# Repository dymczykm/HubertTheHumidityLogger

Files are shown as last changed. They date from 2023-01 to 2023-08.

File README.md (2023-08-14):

# Hubert the Humidity Logger

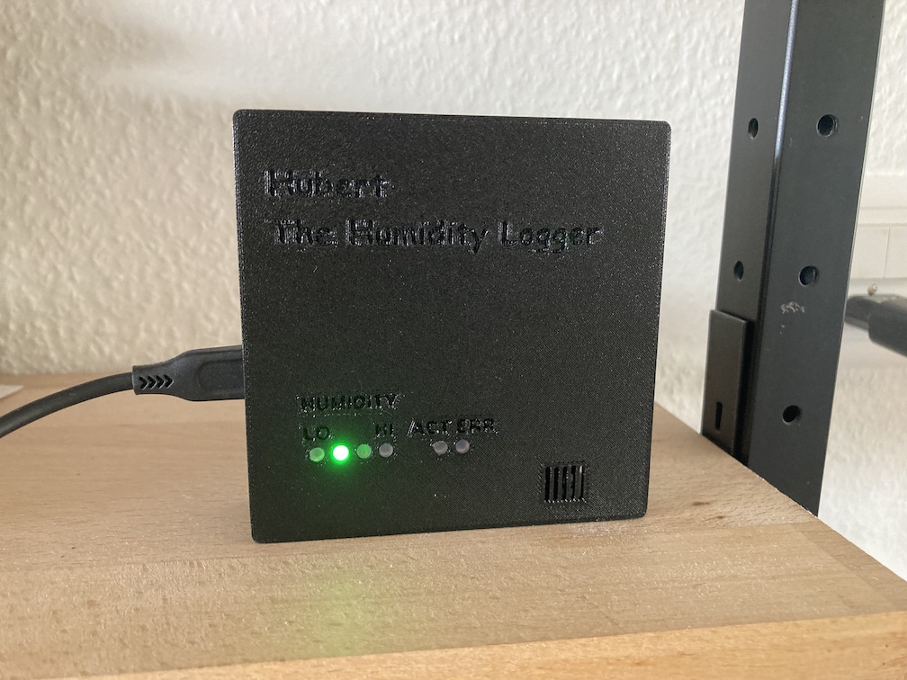
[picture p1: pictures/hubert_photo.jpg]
Photo of Hubert


Huber the Humidity Logger is a project of an IoT device that measures the relative humidity, temperature and pressure and reports it back to a remote server using the built-in 4G modem. I created this project as I couldn't find a device off the shelf that could log humidity using the cellular network and would not cost an arm and a leg.

Hubert can use a HTTP POST action to submit data to virtually any server, either running in the cloud (I tested it with https://io.adafruit.com/) or maintained on your own (my Hubert is submitting data to a Raspberry Pi running InfluxDB).

Hubert is build around (Makerfabs Maduino Zero 4G LTE)[ttps://www.makerfabs.com/maduino-zero-4g-lte-sim7600.html] and loosely inspired by the [DIY Life 4G air quality weather station](https://www.the-diy-life.com/diy-4g-air-quality-and-environment-monitor-record-data-anywhere/).

For more details, please refer to the project page: https://dymczyk.com/hubert-the-humidity-logger

## Hardware

To build Hubert, you need the following components:
- Maduino Zero 4G/LTE board: https://www.makerfabs.com/maduino-zero-4g-lte-sim7600.html (includes an Arduino Zero compatible MCU + a Simcom 7600 modem)
- Hubert breakout board with a bunch of LEDs and a connector for the humidity sensor: KiCad files in `hardware/HumidityLoggerBreakout`
- BME280 sensor compatible with 3.3V supply [(Aliexpress item I used)](https://www.aliexpress.com/item/32862445164.html)
- A SIM card with some data allowance to post the humidity/temperature/pressure measurements

## Firmware

The firmware of Hubert is written in Arduino IDE and is located in `firmware/humidity_logger`.

The firmware does three main things:
1. Triggers the measurement process of BME280
2. POSTs the measurements to a remote server
3. Puts the modem and the MCU to sleep to save power

To adapt it to your application, you mostly need to put the credentials to access the server in `influxdb.h` file:
```
#define USER "xxx"
#define PASSWORD "xxx"
#define DB_URL "xxx"
```

## Remote server

Hubert uses a 4G connection to POST data to an InfluxDB database that resides on a remote server. In my case, it is a Raspberry Pi running continuously InfluxDB and Grafana to visualize the results in a nice dashboard.

## Case

I've designed a 3D printed case for Hubert, you can find the STL files for the top and the bottom in `hardware/case_stl`:

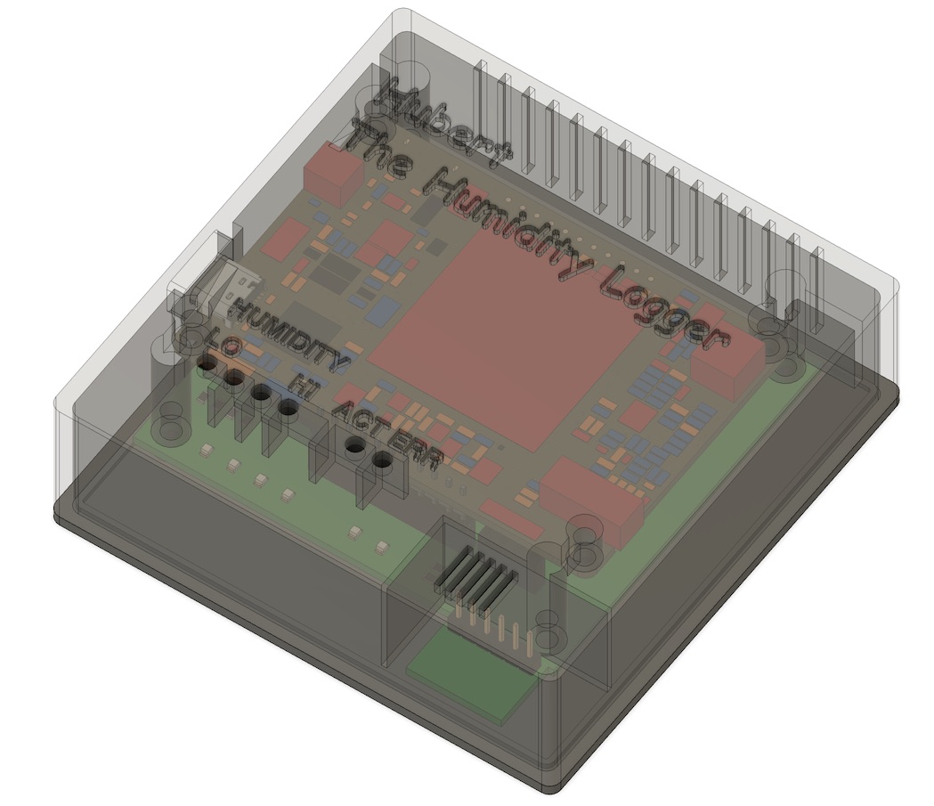
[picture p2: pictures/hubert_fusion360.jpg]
Fusion 360 case design of Hubert


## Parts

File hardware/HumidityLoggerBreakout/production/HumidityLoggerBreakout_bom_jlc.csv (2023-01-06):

Comment | Designator | Footprint | LCSC Part #
22u | C1,C2,C10,C11 | C_0805_2012Metric_Pad1.18x1.45mm_HandSolder | C45783
100n | C3,C4,C6,C7,C8,C9,C12 | C_0805_2012Metric_Pad1.18x1.45mm_HandSolder | C28233
100u | C5 | CP_EIA-3528-12_Kemet-T_Pad1.50x2.35mm_HandSolder | C16133
LED1 | D1 | LED_0805_2012Metric_Pad1.15x1.40mm_HandSolder | C2297
LED2 | D2 | LED_0805_2012Metric_Pad1.15x1.40mm_HandSolder | C2296
5V | D3 | LED_0805_2012Metric_Pad1.15x1.40mm_HandSolder | C2297
3V3 | D4 | LED_0805_2012Metric_Pad1.15x1.40mm_HandSolder | C2297
LED3 | D5 | LED_0805_2012Metric_Pad1.15x1.40mm_HandSolder | C84256
2k | R1,R2,R3,R4 | R_0805_2012Metric_Pad1.20x1.40mm_HandSolder | C17604
1k | R5,R6,R7,R8,R9,R10,R12,R13,R14,R15 | R_0805_2012Metric_Pad1.20x1.40mm_HandSolder | C17513
330 | R11 | R_0805_2012Metric_Pad1.20x1.40mm_HandSolder | C17630
LM317_TO-252 | U1 | TO-252-2 | C75510

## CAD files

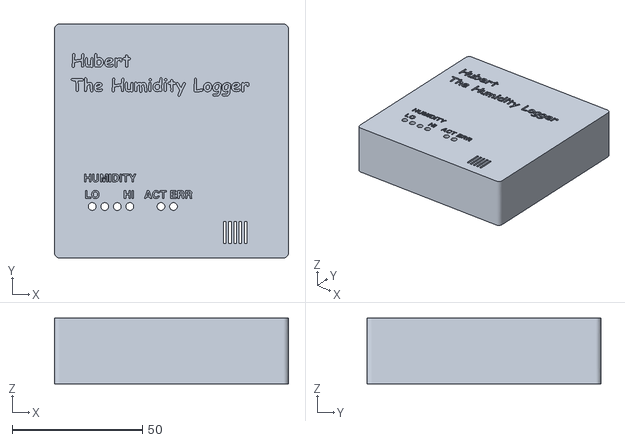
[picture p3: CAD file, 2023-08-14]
hardware/case_stl/HubertCase v27 top.stl
90.0 x 90.0 x 25.3

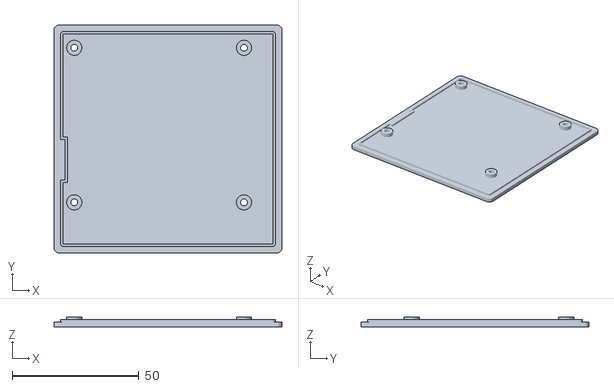
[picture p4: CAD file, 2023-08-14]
hardware/case_stl/HubertCase v28 bottom.stl
90.0 x 90.0 x 4.00

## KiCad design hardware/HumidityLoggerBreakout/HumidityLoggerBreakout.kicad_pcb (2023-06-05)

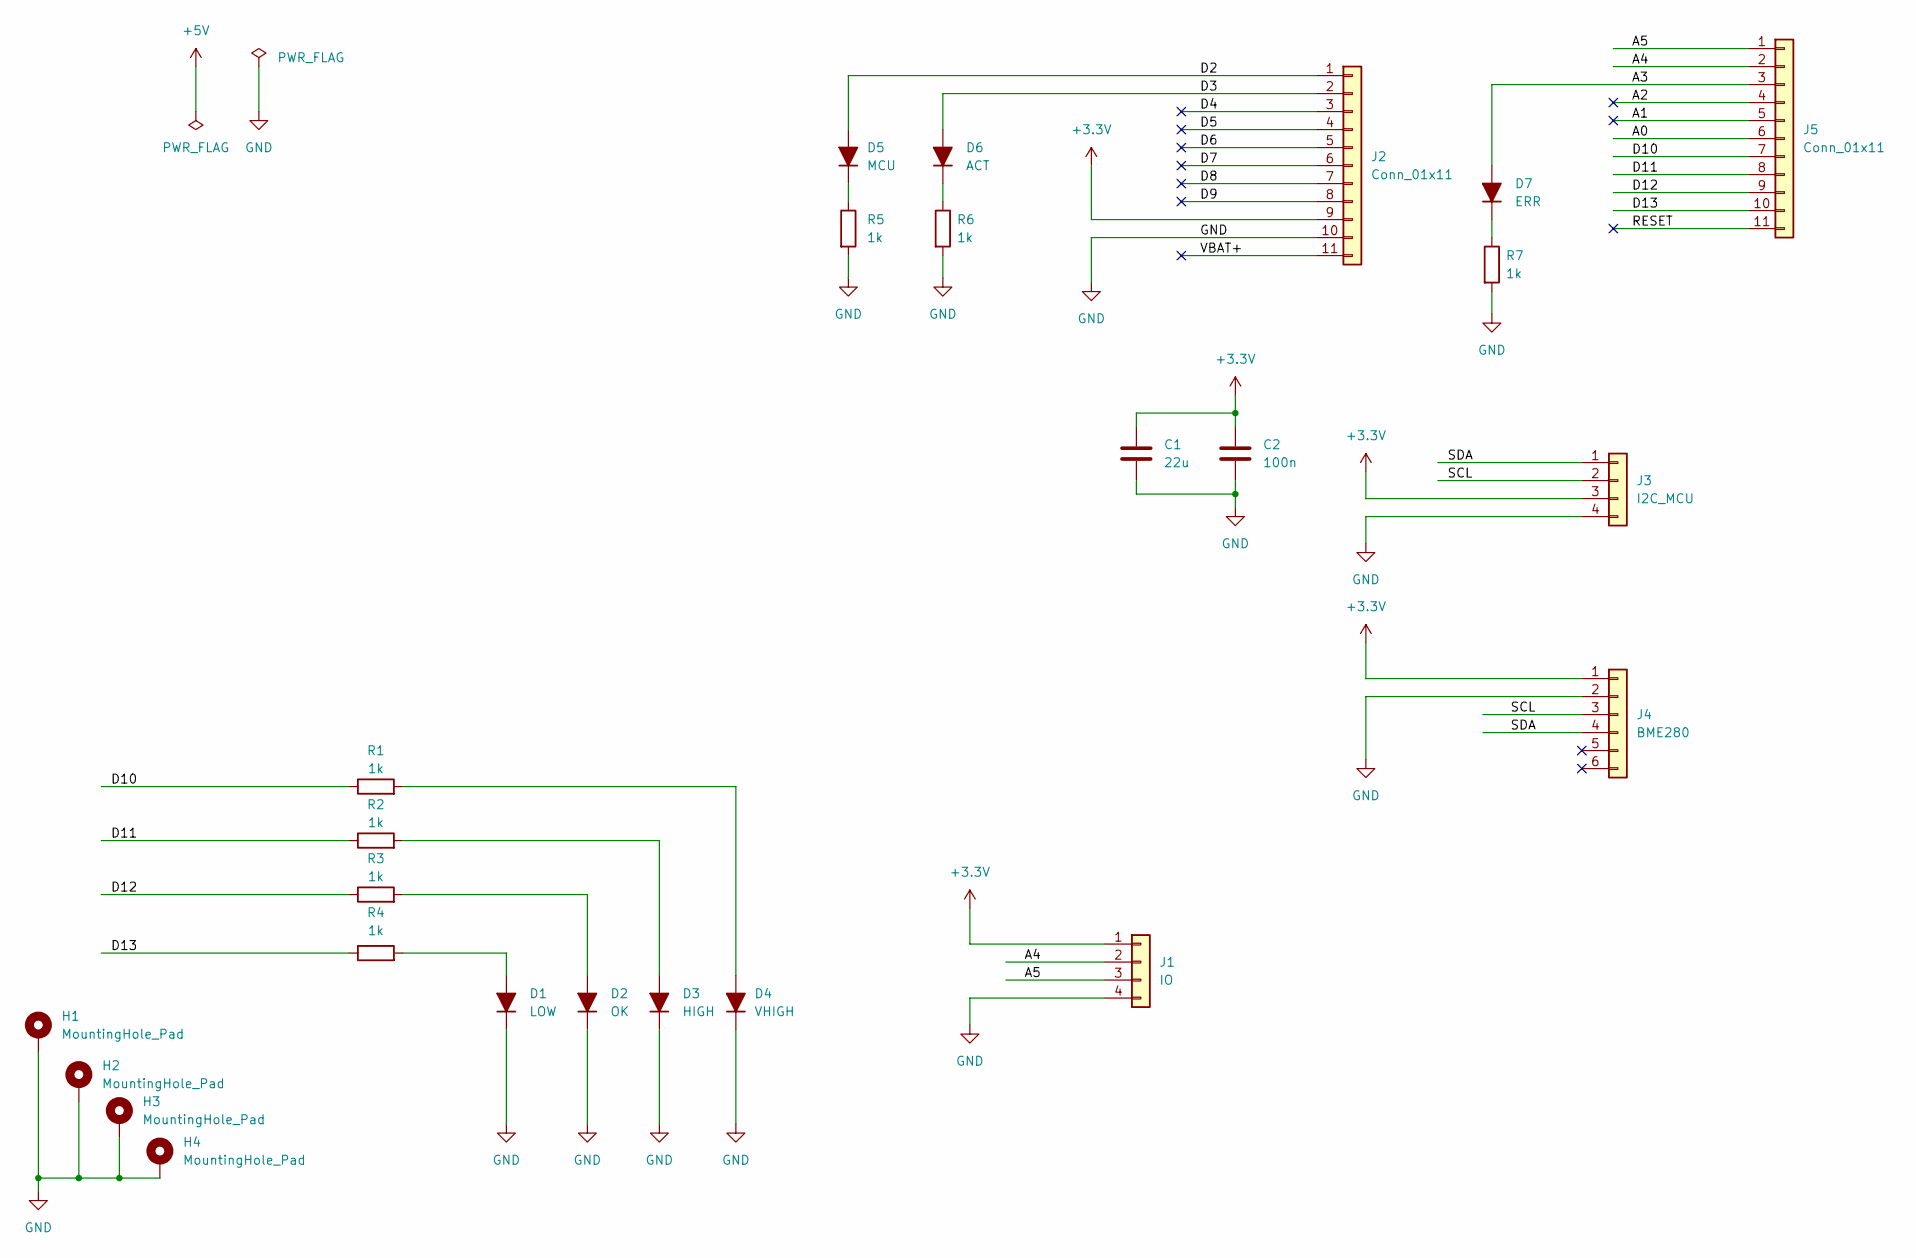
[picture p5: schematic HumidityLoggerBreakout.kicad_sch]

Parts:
C1: 22u; C_0805_2012Metric_Pad1.18x1.45mm_HandSolder; LCSC C45783
C2: 100n; C_0805_2012Metric_Pad1.18x1.45mm_HandSolder; LCSC C28233
D1: LOW; LED_0805_2012Metric_Pad1.15x1.40mm_HandSolder; LCSC C2297
D2: OK; LED_0805_2012Metric_Pad1.15x1.40mm_HandSolder; LCSC C2297
D3: HIGH; LED_0805_2012Metric_Pad1.15x1.40mm_HandSolder; LCSC C2297
D4: VHIGH; LED_0805_2012Metric_Pad1.15x1.40mm_HandSolder; LCSC C2297
D5: MCU; LED_0805_2012Metric_Pad1.15x1.40mm_HandSolder; LCSC C2297
D6: ACT; LED_0805_2012Metric_Pad1.15x1.40mm_HandSolder; LCSC C2296
D7: ERR; LED_0805_2012Metric_Pad1.15x1.40mm_HandSolder; LCSC C84256
H1, H2, H3, H4: MountingHole_Pad; MountingHole_2.7mm_M2.5_Pad_TopBottom
J1: IO; PinHeader_1x04_P2.54mm_Vertical
J2, J5: Conn_01x11; PinSocket_1x11_P2.54mm_Vertical
J3: I2C_MCU; PinSocket_1x04_P2.54mm_Vertical
J4: BME280; PinHeader_1x06_P2.54mm_Vertical
R1, R2, R3, R4, R5, R6, R7: 1k; R_0805_2012Metric_Pad1.20x1.40mm_HandSolder; LCSC C17513

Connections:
+3.3V: C1.1, C2.1, J1.1, J2.9, J3.3, J4.1
/A0: J5.6
/A1: J5.5
/A2: J5.4
/A3: D7.2 (A), J5.3
/A4: J1.2, J5.2
/A5: J1.3, J5.1
/D2: D5.2 (A), J2.1
/D3: D6.2 (A), J2.2
/D4: J2.3
/D5: J2.4
/D6: J2.5
/D7: J2.6
/D8: J2.7
/D9: J2.8
/D10: J5.7, R1.1
/D11: J5.8, R2.1
/D12: J5.9, R3.1
/D13: J5.10, R4.1
/RESET: J5.11
/SCL: J3.2, J4.3
/SDA: J3.1, J4.4
/VBAT+: J2.11
GND: C1.2, C2.2, D1.1 (K), D2.1 (K), D3.1 (K), D4.1 (K), H1.1, H2.1, H3.1, H4.1, J1.4, J2.10, J3.4, J4.2, R5.2, R6.2, R7.2
unnamed: D1.2 (A), R4.2
unnamed: D2.2 (A), R3.2
unnamed: D3.2 (A), R2.2
unnamed: D4.2 (A), R1.2
unnamed: D5.1 (K), R5.1
unnamed: D6.1 (K), R6.1
unnamed: D7.1 (K), R7.1

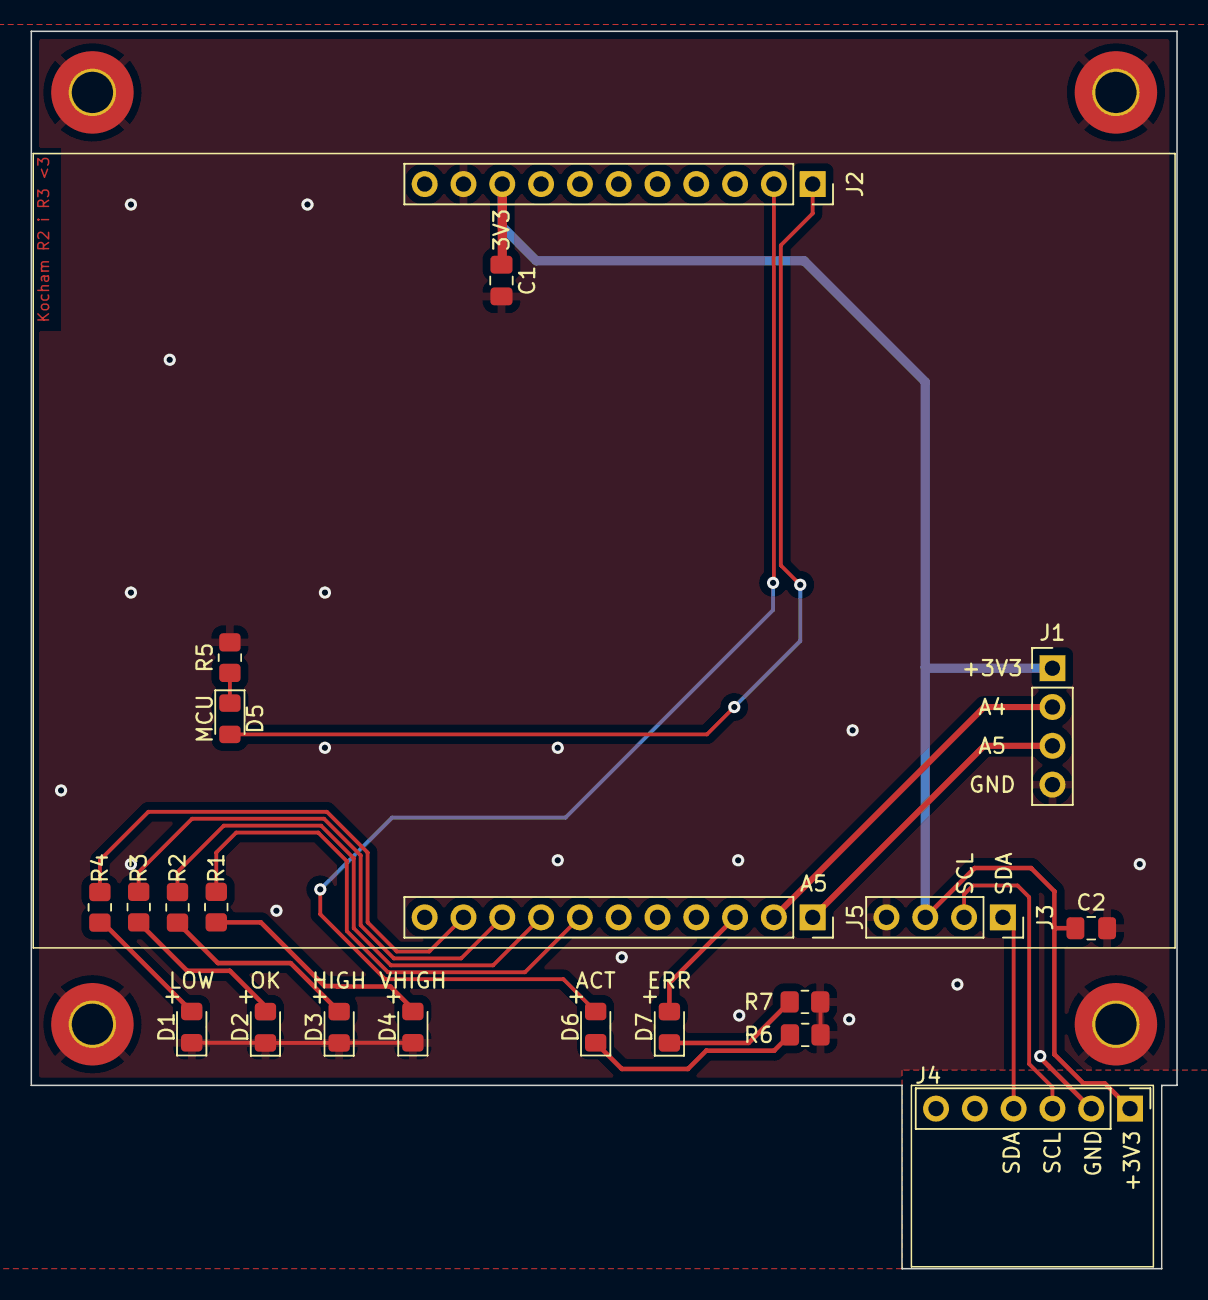
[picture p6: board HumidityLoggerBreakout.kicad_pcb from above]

Board: 2 copper layers, 75.0 x 81.0 mm, 25 parts (0 on the bottom side), 20 nets.

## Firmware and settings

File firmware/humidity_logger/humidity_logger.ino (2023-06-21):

#include <Adafruit_BME280.h>

#include "ArduinoLowPower.h"

#include "influxdb.h"
#include "sim7600.h"

#define DEBUG 0

#define RH_VHIGH_PIN 10
#define RH_HIGH_PIN 11
#define RH_OK_PIN 12
#define RH_LOW_PIN 13

#define ACT_LED_PIN 3
#define ERR_LED_PIN 17

Adafruit_BME280 bme280;

void initIo() {
  pinMode(RH_VHIGH_PIN, OUTPUT); // Very high RH indicator.
  pinMode(RH_HIGH_PIN, OUTPUT); // High RH indicator.
  pinMode(RH_OK_PIN, OUTPUT); // OK RH indicator.
  pinMode(RH_LOW_PIN, OUTPUT); // Low RH indicator.

  pinMode(ACT_LED_PIN, OUTPUT); // ACT.
  pinMode(ERR_LED_PIN, OUTPUT); // ERR.
}

void outputRhLed(const float humidity) {
  // Turn off all LEDs.
  digitalWrite(RH_VHIGH_PIN, 0);
  digitalWrite(RH_HIGH_PIN, 0);
  digitalWrite(RH_OK_PIN, 0);
  digitalWrite(RH_LOW_PIN, 0);

  // Turn on the correct LEDs.
  if (humidity > 70) {
    digitalWrite(RH_VHIGH_PIN, 1);
    digitalWrite(RH_HIGH_PIN, 1);
    digitalWrite(RH_OK_PIN, 1);
    digitalWrite(RH_LOW_PIN, 1);
  } else if (humidity > 60) {
    digitalWrite(RH_HIGH_PIN, 1);
    digitalWrite(RH_OK_PIN, 1);
    digitalWrite(RH_LOW_PIN, 1);
  } else if (humidity > 30) {
    digitalWrite(RH_OK_PIN, 1);
    digitalWrite(RH_LOW_PIN, 1);
  } else {
    digitalWrite(RH_LOW_PIN, 1);
  }
}

void sleepAndBlinkEverySecond(const unsigned long seconds, const int pin_number) {
  for (int i = 0; i < seconds; ++i) {
    // Sleep for 5 minutes.
    LowPower.deepSleep(990);
    
    if (i % 2 == 0) {
      // Only blink on even seconds.
      digitalWrite(pin_number, 1);
    }
    delay(10);
    digitalWrite(pin_number, 0);
  } 
}

void setup() {
  SerialUSB.begin(115200);
  while (DEBUG && !SerialUSB)
  {
    ; // wait for Arduino serial Monitor port to connect
  }
  
  SerialUSB.println(F("\n\nHi."));

  initIo();

  digitalWrite(ACT_LED_PIN, 1);
  digitalWrite(ERR_LED_PIN, 1);

  delay(100);
  digitalWrite(RH_VHIGH_PIN, 1);
  delay(100);
  digitalWrite(RH_HIGH_PIN, 1);
  delay(100);
  digitalWrite(RH_OK_PIN, 1);
  delay(100);
  digitalWrite(RH_LOW_PIN, 1);
  delay(200);
  digitalWrite(RH_VHIGH_PIN, 0);
  digitalWrite(RH_HIGH_PIN, 0);
  digitalWrite(RH_OK_PIN, 0);
  digitalWrite(RH_LOW_PIN, 0);
  
  initModem();
  SerialUSB.println(F("LTE init complete."));

  if (!bme280.begin(BME280_ADDRESS_ALTERNATE)) {
    digitalWrite(ACT_LED_PIN, 0);
    while(1) {
      digitalWrite(ERR_LED_PIN, !digitalRead(ERR_LED_PIN));
      delay(50);
    }
  }

  bme280.setSampling(Adafruit_BME280::MODE_FORCED,
                    Adafruit_BME280::SAMPLING_X1,   // temperature
                    Adafruit_BME280::SAMPLING_X1,   // pressure
                    Adafruit_BME280::SAMPLING_X1,   // humidity
                    Adafruit_BME280::FILTER_OFF);

  digitalWrite(ACT_LED_PIN, 0);
  digitalWrite(ERR_LED_PIN, 0);
  
  SerialUSB.println(F("Setup complete."));
}

void loop() {
  digitalWrite(ACT_LED_PIN, 0);
  digitalWrite(ERR_LED_PIN, 0);
  modemWakeup();

  bme280.takeForcedMeasurement();
  delay(200);
  
  const float temperature = bme280.readTemperature();
  const float pressure_hpa = bme280.readPressure() / 100;
  const float humidity = bme280.readHumidity(); 

  outputRhLed(humidity);  

  SerialUSB.println("");
  SerialUSB.print("Temp: ");
  SerialUSB.print(temperature);
  SerialUSB.println("C");
  SerialUSB.print("Humidity: ");
  SerialUSB.print(humidity);
  SerialUSB.println("%");
  SerialUSB.print("Pressure: ");
  SerialUSB.print(pressure_hpa);
  SerialUSB.println("hPa");

  bool success = false;
  if (postToDatabase(F("temp_rh"), F("garaz"), temperature, humidity, pressure_hpa)) {
      digitalWrite(ACT_LED_PIN, 1);
      success = true;
  } else {
      digitalWrite(ERR_LED_PIN, 1);
      success = false;
  }

  modemSleep();
  LowPower.deepSleep(2000);

  digitalWrite(ACT_LED_PIN, 0);
  digitalWrite(ERR_LED_PIN, 0);

  // Sleep for 5 minutes (5*60 = 300 seconds).
  sleepAndBlinkEverySecond(300, success ? ACT_LED_PIN : ERR_LED_PIN);
}

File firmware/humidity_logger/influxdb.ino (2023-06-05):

#include "influxdb.h"

bool postToDatabase(String feed, const String& location, const float& temperature, const float& humidity, const float& pressure) {
  // Build the URL first.
  const String url_str = DB_URL;
  const String key_str = (String)F("Authorization: Token ") + USER + ":" + PASSWORD;
  const String data_str = "temp_rh,location=" + location + " temp=" + (String)temperature + ",rh=" + (String)humidity + ",pressure=" + (String)pressure;

  const int post_code = httpPost(url_str, F("application/json"), key_str, data_str);
  if (post_code == 200 || post_code == 201 || post_code == 204) {
    SerialUSB.println("HTTP POST success.");
    return true;
  } else {
    SerialUSB.println("HTTP POST fail: " + (String)post_code);
    return false;
  }
}

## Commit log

2023-01-05 Feed and pump control work.
2023-01-06 Added the breakout PCB for Maduino.
    [HumidityLoggerBreakout.kicad_pcb, HumidityLoggerBreakout.kicad_sch]
2023-01-06 First prototype production files.
    [HumidityLoggerBreakout-B_Cu.gbl, HumidityLoggerBreakout-B_Mask.gbs, HumidityLoggerBreakout-B_Paste.gbp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]
2023-01-06 Minor corrections.
    [HumidityLoggerBreakout.kicad_pcb]
2023-01-19 The big connectors were flipped :(
    [HumidityLoggerBreakout.kicad_pcb]
2023-01-19 Fixed the connectors to Maduino.
    [HumidityLoggerBreakout.kicad_pcb]
2023-05-22 Modified the schematic to drop unnecessary features.
    [HumidityLoggerBreakout.kicad_pcb, HumidityLoggerBreakout.kicad_sch]
2023-05-26 WIP of the new version.
    [HumidityLoggerBreakout.kicad_sch]
2023-05-30 WIP on the board.
    [HumidityLoggerBreakout.kicad_pcb, HumidityLoggerBreakout.kicad_sch]
2023-06-05 After updating the firmware USERDATA can be used again.
    [HumidityLoggerBreakout.kicad_pcb]
2023-06-10 Got the sensor and the LEDs to work.
2023-06-11 Added sleeping + LED blink.
2023-06-13 Red LED is blinking after the POST fails.
    [humidity_logger.ino]
2023-06-21 RH LED test on boot.
2023-08-14 Updated the README.
    [HubertCase v27 top.stl, HubertCase v28 bottom.stl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]
